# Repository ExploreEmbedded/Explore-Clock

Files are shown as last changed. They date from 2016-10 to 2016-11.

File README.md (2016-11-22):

# FunTime
FunTime is a simple DIY clock kit, that doubles up as automatic night lamp. While building this kit we learn about how time is computed, converted to secs, mins, hours, days and eventually into years! We will also learn about measuring light and controlling a LED depending on time and light. The end goal is build a cool wall clock, use the time and the light intensity to turn on the night lamp. It will take about an hour to solder and assemble the kit.

Get one at:
https://www.exploreembedded.com/product/funTime 

Acrylic Design 
funtime1
PCB

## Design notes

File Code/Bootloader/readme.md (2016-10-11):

Flash the bootloader in the adjacent directory and set the fuse bits as below:
 
 HIGH 0xDA
 LOW 0xE2
 Extended 0xFF

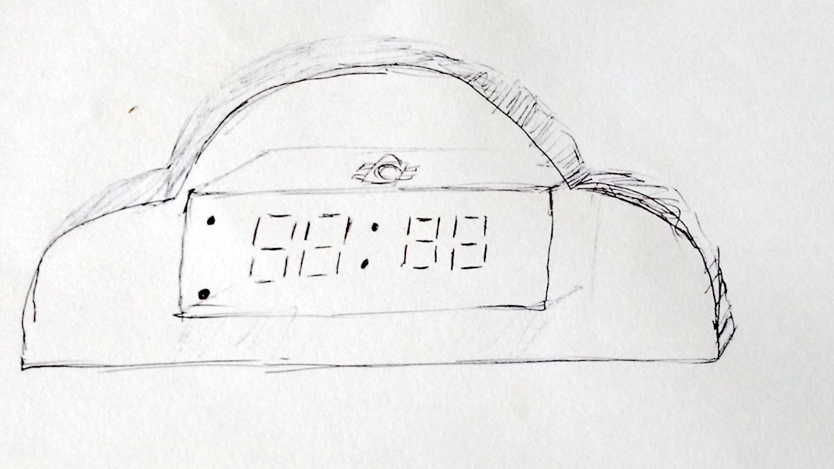
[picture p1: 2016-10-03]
Enclosure/.picasaoriginals/funTime.jpg

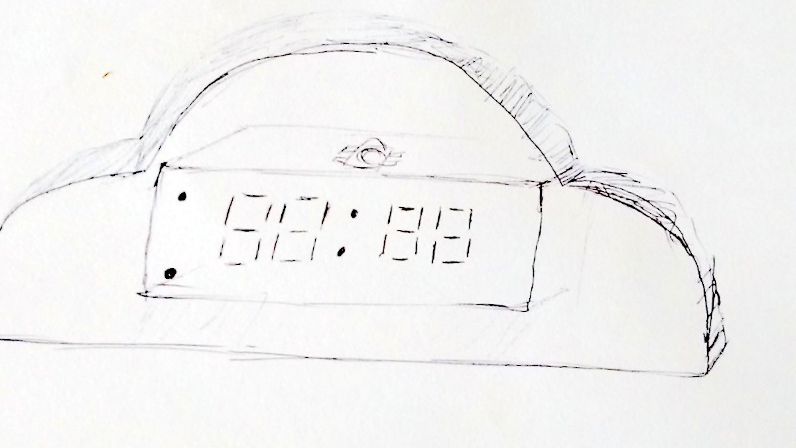
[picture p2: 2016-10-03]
Enclosure/funTime.jpg

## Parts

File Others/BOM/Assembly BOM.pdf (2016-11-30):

SR No. | Designator | Value | Quantity
1 | AFF1 | 4 Digit 7 Segment display ( white ) | 1
2 | C1 | 0.1uF Disc Capacitor | 1
3 | P1 | 01X07 Female Pin Header | 1
4 | R1,R3 | 100K Resistors | 2
5 | R2,R5,R8 | 10K Resistors | 3
6 | R4 | 470E Resistors | 1
7 | R7 | 1K Resistors | 2
8 | R6 | Link (0 ohm) | 1
9 | BT1 | Coin Cell Battery Holder | 1
10 | CON1 | DC Jack | 1
11 | D1 | 5V1 Zener Diode | 1
12 | D2 | 3mm LED | 1
13 | D3 | 8mm 0.5W Straw hat LED | 1
14 | D4,D5 | 1N4148 Diodes | 2
15 | IC1 | ATMEGA328P Controller | 1
16 | Q1 | BC547 NPN Transistor | 1
17 | Q2 | BD139 NPN Transistor | 1
18 | R9 | 47E Resistor | 1
19 | SP1 | Small Buzzer | 1
20 | SW1,SW2 | 25mm Long Tactile Switch | 2
21 | U1 | LDR | 1
22 | Y1 | 32.768KHz Crystal | 1
23 | P2,P3,P4,P5 | M3 Mounting screws and nuts | 8 pair

## FunTime v0.1

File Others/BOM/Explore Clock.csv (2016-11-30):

SR No. | Designator | Value | Quantity
1 | AFF1 | 4 Digit 7 Segment display ( white ) | 1
2 | C1 | 0.1uF Disc Capacitor | 1
3 | P1 | 01X07 Female Pin Header | 1
4 | R1,R3 | 100K Resistors | 2
5 | R2,R5,R8 | 10K Resistors | 3
6 | R4 | 470E Resistors | 1
7 | R6,R7 | 1K Resistors | 2
8 | BT1 | Coin Cell Battery Holder | 1
9 | CON1 | DC Jack | 1
10 | D1 | 5V1 Zener Diode | 1
11 | D2 | 3mm LED | 1
12 | D3 | 8mm 0.5W Straw hat LED | 1
13 | D4,D5 | 1N4148 Diodes | 2
14 | IC1 | ATMEGA328P Controller | 1
15 | Q1 | BC547 NPN Transistor | 1
16 | Q2 | BD139 NPN Transistor | 1
17 | R9 | 47E Resistor | 1
18 | SP1 | Small Buzzer | 1
19 | SW1,SW2 | 25mm Long Tactile Switch | 2
20 | U1 | LDR | 1
21 | Y1 | 32.768KHz Crystal | 1
22 | P2,P3,P4,P5 | M3 Mounting screws and nuts | 8 pair

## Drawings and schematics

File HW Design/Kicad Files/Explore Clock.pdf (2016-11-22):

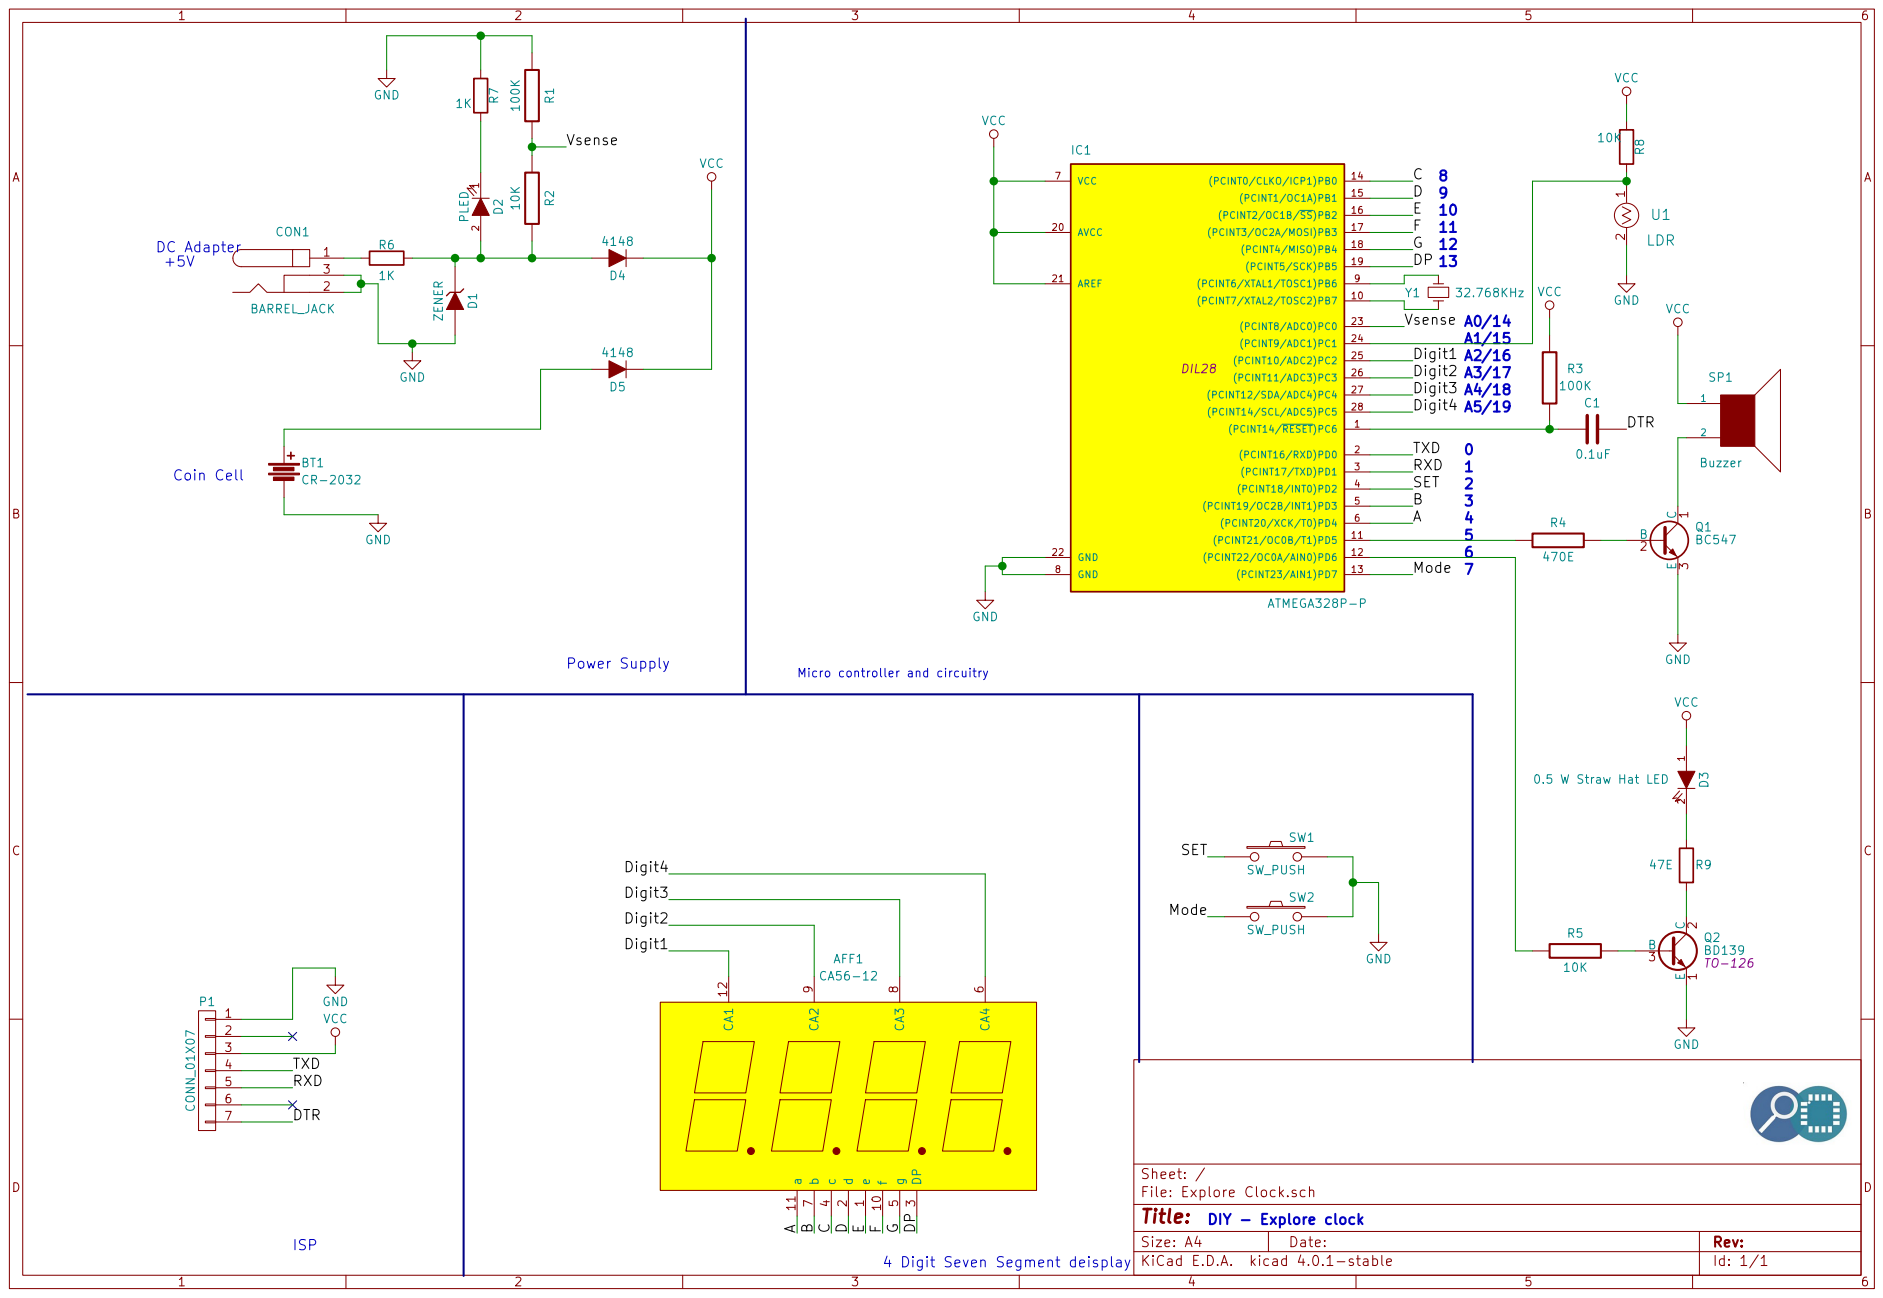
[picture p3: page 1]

File: Explore Clock.sch Sheet: /
Id: 1/1 Title:

4 Digit Seven Segment deisplay

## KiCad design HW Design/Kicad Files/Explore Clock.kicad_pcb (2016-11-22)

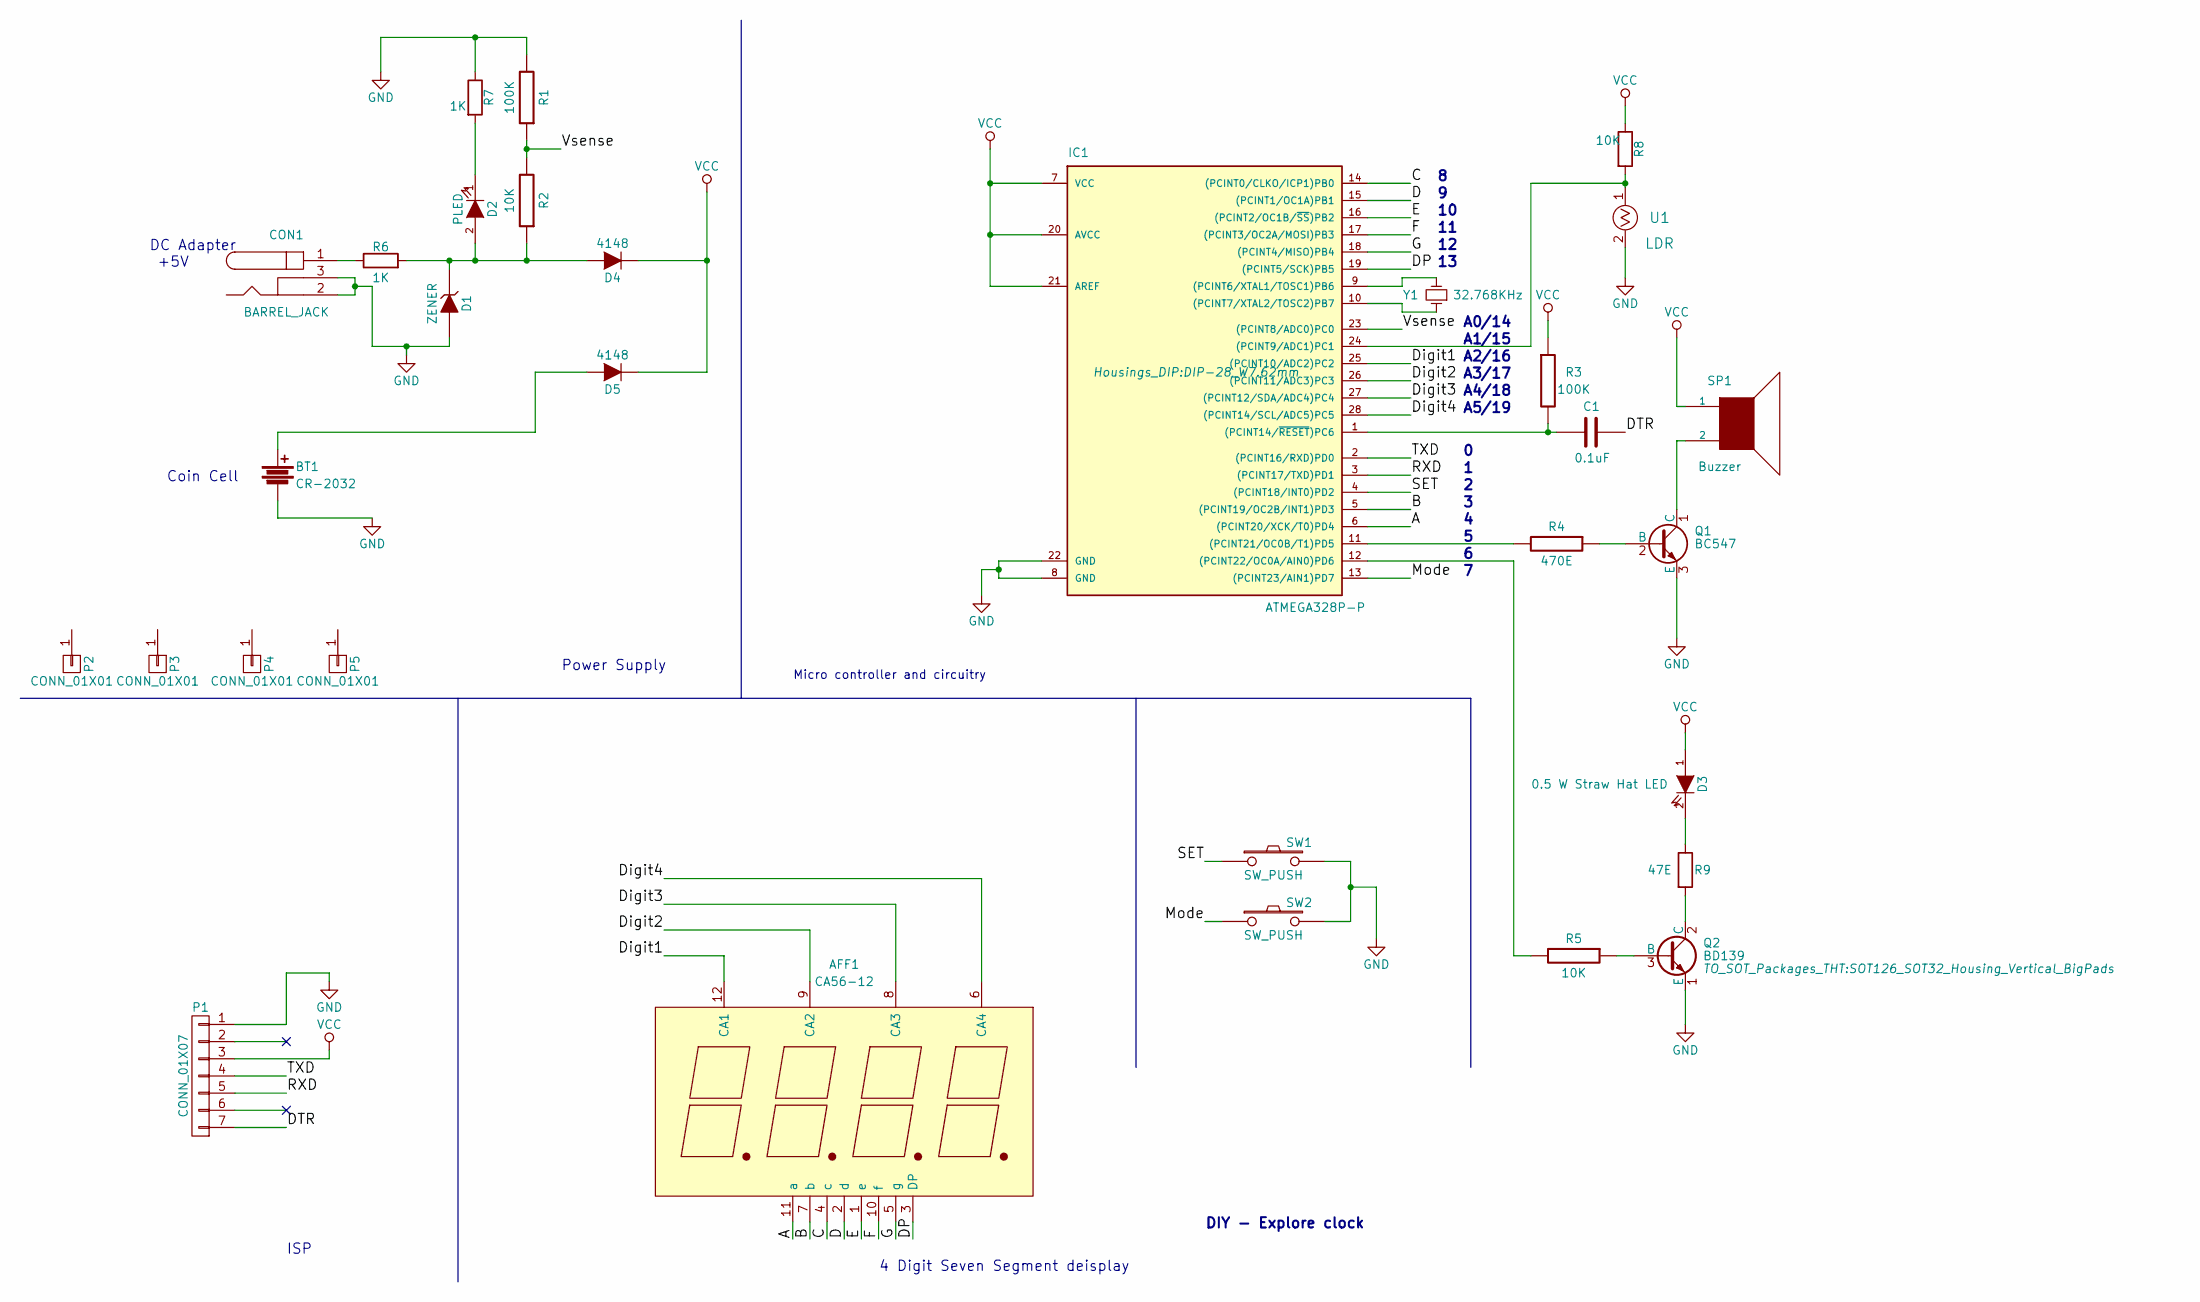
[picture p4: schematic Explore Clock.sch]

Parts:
AFF1: CA56-12; Cx56-12
BT1: CR-2032; BATT_rtc_XL
C1: 0.1uF; C_Disc_D3_P2.5
CON1: BARREL_JACK; JACK_ALIM
D1: ZENER; Diode_DO-41_SOD81_Horizontal_RM10
D2: PLED; LED-3MM
D3: 0.5 W Straw Hat LED; C_Disc_D3_P2.5
D4, D5: 4148; Diode_DO-41_SOD81_Horizontal_RM10
IC1: ATMEGA328P-P; DIP-28_W7.62mm
P1: CONN_01X07; Pin_Header_Straight_1x07
P2, P3, P4, P5: CONN_01X01; M3_mounting
Q1: BC547; TO-92_Molded_Narrow
Q2: BD139; SOT126_SOT32_Housing_Vertical_BigPads
R1, R3: 100K; Resistor_Horizontal_RM10mm
R2, R5, R8: 10K; Resistor_Horizontal_RM10mm
R4: 470E; Resistor_Horizontal_RM10mm
R6, R7: 1K; Resistor_Horizontal_RM10mm
R9: 47E; Resistor_Horizontal_RM10mm
SP1: Buzzer; BUZ3-5
SW1, SW2: SW_PUSH; SW_PUSH_SMALL
U1: LDR; C_Disc_D3_P2.5
Y1: 32.768KHz; RTC_Crystal

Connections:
/A: AFF1.11 (a), IC1.6 ((PCINT20/XCK/T0)PD4)
/B: AFF1.7 (b), IC1.5 ((PCINT19/OC2B/INT1)PD3)
/C: AFF1.4 (c), IC1.14 ((PCINT0/CLKO/ICP1)PB0)
/D: AFF1.2 (d), IC1.15 ((PCINT1/OC1A)PB1)
/DP: AFF1.3 (DP), IC1.19 ((PCINT5/SCK)PB5)
/DTR: C1.1, P1.7
/Digit1: AFF1.12 (CA1), IC1.25 ((PCINT10/ADC2)PC2)
/Digit2: AFF1.9 (CA2), IC1.26 ((PCINT11/ADC3)PC3)
/Digit3: AFF1.8 (CA3), IC1.27 ((PCINT12/SDA/ADC4)PC4)
/Digit4: AFF1.6 (CA4), IC1.28 ((PCINT14/SCL/ADC5)PC5)
/E: AFF1.1 (e), IC1.16 ((PCINT2/OC1B/~SS~)PB2)
/F: AFF1.10 (f), IC1.17 ((PCINT3/OC2A/MOSI)PB3)
/G: AFF1.5 (g), IC1.18 ((PCINT4/MISO)PB4)
/Mode: IC1.13 ((PCINT23/AIN1)PD7), SW2.1
/RXD: IC1.3 ((PCINT17/TXD)PD1), P1.5
/SET: IC1.4 ((PCINT18/INT0)PD2), SW1.1
/TXD: IC1.2 ((PCINT16/RXD)PD0), P1.4
/Vsense: IC1.23 ((PCINT8/ADC0)PC0), R1.1, R2.2
GND: BT1.2, CON1.2, CON1.3, D1.2 (A), IC1.8 (GND), IC1.22 (GND), P1.1, Q1.3 (E), Q2.1 (E), R1.2, R7.1, SW1.2, SW2.2, U1.2
unnamed: BT1.1, D5.2 (A)
unnamed: C1.2, IC1.1 ((PCINT14/~RESET~)PC6), R3.2
unnamed: CON1.1, R6.1
unnamed: D1.1 (K), D2.2 (A), D4.2 (A), R2.1, R6.2
unnamed: D2.1 (K), R7.2
unnamed: D3.2 (K), R9.1
unnamed: IC1.9 ((PCINT6/XTAL1/TOSC1)PB6), Y1.2
unnamed: IC1.10 ((PCINT7/XTAL2/TOSC2)PB7), Y1.1
unnamed: IC1.11 ((PCINT21/OC0B/T1)PD5), R4.2
unnamed: IC1.12 ((PCINT22/OC0A/AIN0)PD6), R5.2
unnamed: IC1.24 ((PCINT9/ADC1)PC1), R8.2, U1.1
unnamed: Q1.1 (C), SP1.2
unnamed: Q1.2 (B), R4.1
unnamed: Q2.2 (C), R9.2
unnamed: Q2.3 (B), R5.1
VCC: D3.1 (A), D4.1 (K), D5.1 (K), IC1.7 (VCC), IC1.20 (AVCC), IC1.21 (AREF), P1.3, R3.1, R8.1, SP1.1

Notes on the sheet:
DIY - Explore clock
DC Adapter +5V
Coin Cell
Power Supply
ISP
4 Digit Seven Segment deisplay
Micro controller and circuitry
/14
/15
/16
/17
/18
/19

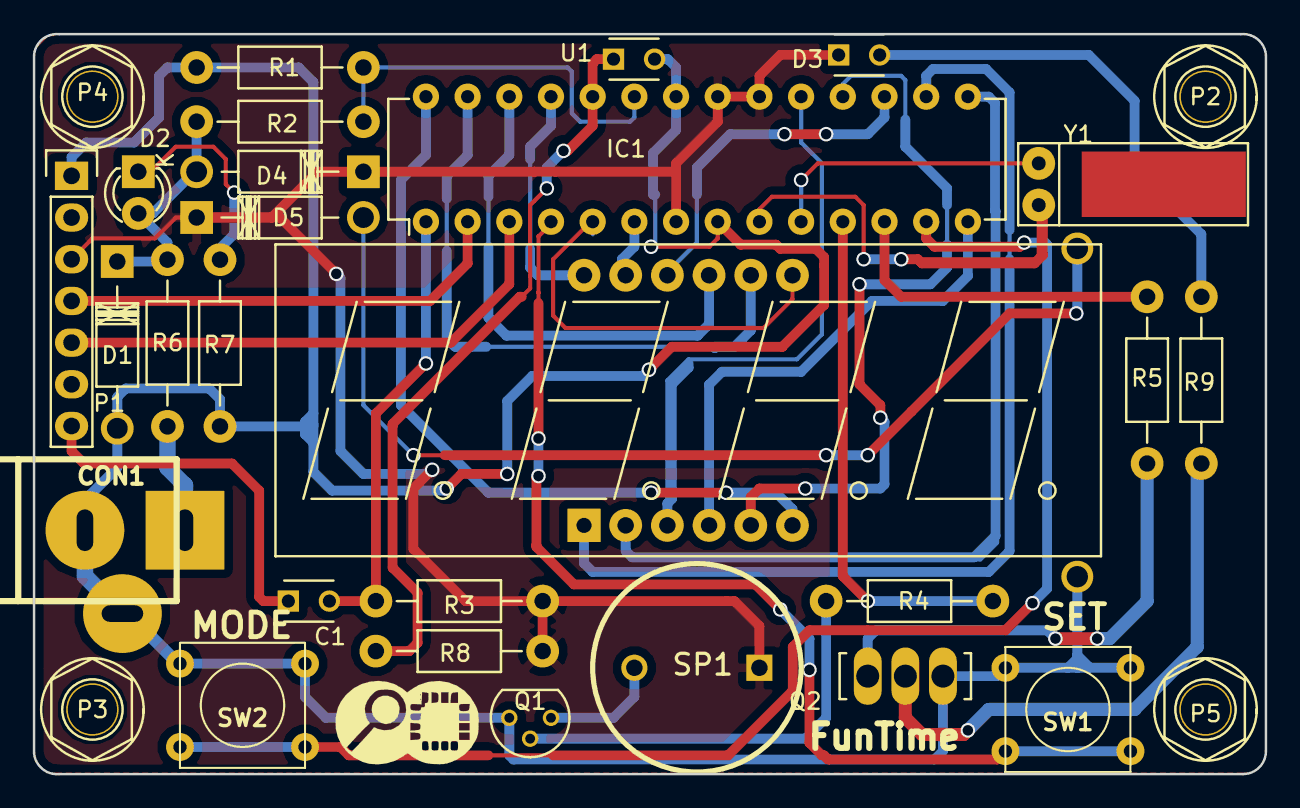
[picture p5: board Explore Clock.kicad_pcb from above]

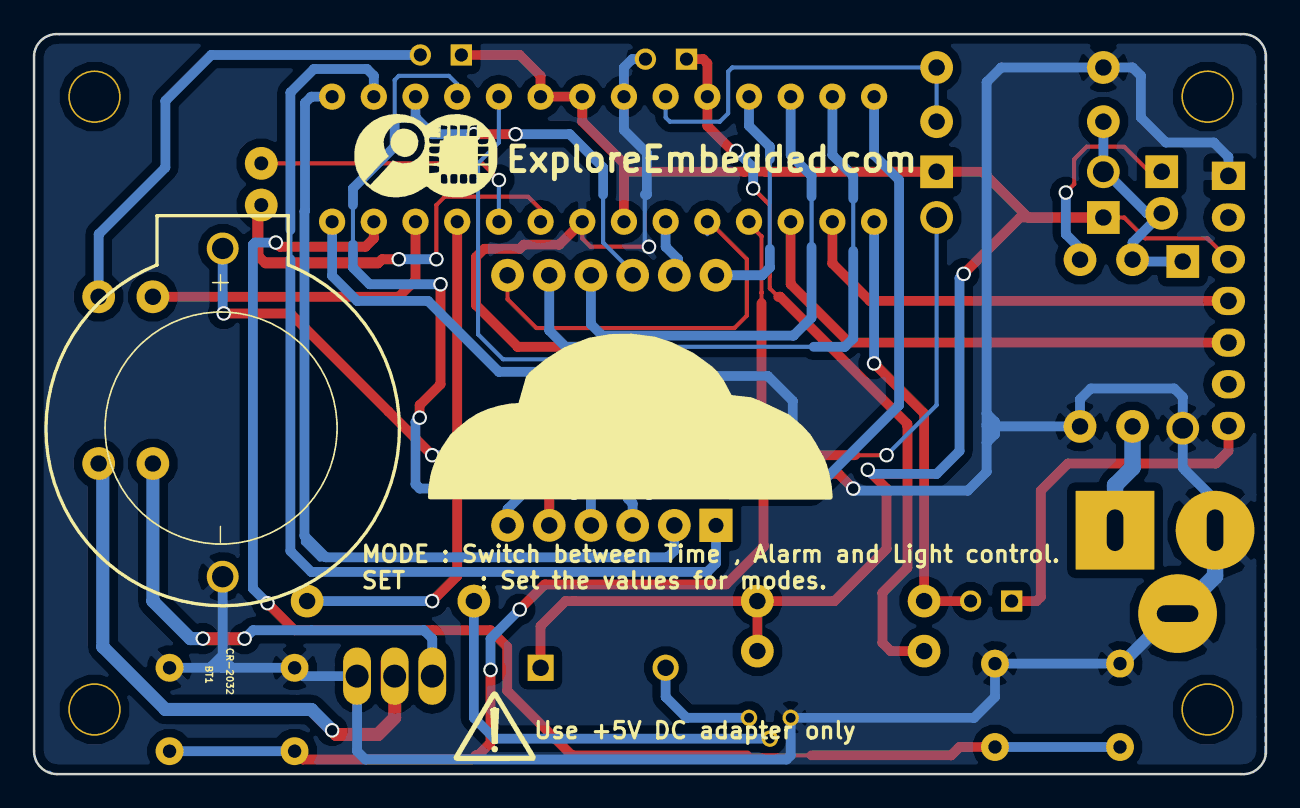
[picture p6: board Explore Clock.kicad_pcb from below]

Board: 2 copper layers, 75.1 x 45.1 mm, 33 parts (2 on the bottom side), 35 nets.

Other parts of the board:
P14, P14#2: CONN_01X01; Logo_8

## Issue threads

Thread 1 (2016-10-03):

Design Considerations

Xplorer001, 2016-10-03:
- [ ] Bigger segments(1.2 inch ?) will aid better visibility. If not readily available we can go with .56 inch ones.
- [ ] Ideas for Acrylic Cases.
- [ ] Test driving circuit for .5W led, that acts as night lamp

raghavendrahassy, 2016-10-03:
0.5W straw hat LED driving circuit.

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

raghavendrahassy, 2016-10-13:
Bigger segments(1.2 inch ?) will aid better visibility. If not readily available we can go with .56 inch ones.
This can be implemented in the next the revision.
 Ideas for Acrylic Cases.
Done
 Test driving circuit for .5W led, that acts as night lamp
Designed using BD139 Transistor

Closed 2016-10-13.

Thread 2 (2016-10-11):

Pin Assigments

Xplorer001, 2016-10-11:
- Change **SET** PIN to Arduino **PIN 2** (PORTD2) for using interrupt to walk from sleep and check time.
- Change **A** to Arduino **PIN 4**
- Set Value of R1 TO 100K and R2 to 10K
- Add zener diode of 5.1v break down across dc adapter input.

raghavendrahassy, 2016-10-13:
Changes has been done

Closed 2016-10-13.

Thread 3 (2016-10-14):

Modifications needs to be done for acrylic case

raghavendrahassy, 2016-10-14:
@sharanago  :
1. Modify case design as per finalised PCB.
2. Design cases for 5mm thickness acrylic sheet.
3. Routing should be 1.5mm to 2mm inside the edges of the acrylic sheet.
4. Maintain above 2.5 mm clearance between front and rear plate.
5. Provide 2 openings on the top plate for 0.5W LED and LDR.

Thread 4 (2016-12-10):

List of Modifications needs be done

raghavendrahassy, 2016-12-10:
- Buzzer ploarity needs to be added on silkscreen.

-  Coin cell battery needs to be placed out of display surrounding.

-  Controller base pin 1 notch should be added on silkscreen and its need little clearance from
the display.

- BD139 Silkscreen orientation.

- LDR pin spacing needs to be increased.

- Straw hat LED footprint needs to be changed, also indicate the polarity on silkscreen.

- Shift R5 and R9 resistors from coin cell battery area.

- Change the R6 value from 1K to 0Ohm.

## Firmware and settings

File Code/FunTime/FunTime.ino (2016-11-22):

/*
	

 Firmware for FunTime DIY wall clock.  The clock is based on the the popular Atmega328 running on Internal 8Mhz oscillator. The clock uses Timer 1 with 32.686kHz ocillator to keep time. The clock is powered by 5V DC adapter, in case
 of power outage, it automatically switches to the CR2032 coin cell battery and enters sleep mode for power saving.

 The night lamp, simply turns on if it is dark. You can set the value depending on lighting conditions of your house. The higher the value of 
 sensor, the darker is the room.
 
 For more:
 https://github.com/ExploreEmbedded/FunTime 
 
 

 Internal 8MHz
 Clock div 8 cleared
 Brown out detect disabled
 BOOTRST set
 BOOSZ = 1024 
 This is to save power and open up the XTAL pins for use with a 38.786kHz external osc.
 
 So the fuse bits I get using AVR studio:
 HIGH 0xDA
 LOW 0xE2
 Extended 0xFF  
 
 3,600 seconds in an hour
 1 time check per hour, 2 seconds at 13mA
 3,598 seconds @ 1.2uA
 (3598 / 3600) * 0.0012mA + (2 / 3600) * 13mA = 0.0084mA used per hour
 
 200mAh / 0.0084mA = 23,809hr = 992 days = 2.7 years
 

 References and Credits:
 Inspirted by the BigTime kit from Sparkfun. 
 https://github.com/sparkfun/BigTime 

 To Do:

 Add alarm functionality.
 Option to set light intensity with the switches. The light sensor value can be linearly mapped from 0 to 99. 
 
 
 */
#include "main.h"

#include <avr/sleep.h> //Needed for sleep_mode
#include <avr/power.h> //Needed for powering down perihperals such as the ADC/TWI and Timers



//Set the 12hourMode to false for military/world time. Set it to true for American 12 hour time.
int TwelveHourMode = true;

//Set this variable to change how long the time is shown on the watch face. In milliseconds so 1677 = 1.677 seconds
int show_time_length = 5000;
int show_the_time = false;

//You can set always_on to true and the display will stay on all the time
//This will drain the battery in about 15 hours 
int always_on = false;

long seconds = 55;
int minutes = 19;
int hours = 10;

//Careful messing with the system color, you can damage the display if
//you assign the wrong color. If you're in doubt, set it to red and load the code,
//then see what the color is.
#define RED  1
#define GREEN 2
#define BLUE  3
#define YELLOW  4
int systemColor = RED;
int display_brightness = 15000; //A larger number makes the display more dim. This is set correctly below.


//Power Source

#define BATTERY 0
#define DC 1

boolean pwrSource =  BATTERY ;

//-=-=-=-=-=-=-=-=-=-=-=-=-=-=-=-=-=-=
//Pin definitions
int digit1 = A2; //Display pin 1
int digit2 = A3; //Display pin 2
int digit3 = A4; //Display pin 6
int digit4 = A5; //Display pin 8

int segA = 4; //Display pin 14
int segB = 3; //Display pin 16
int segC = 8; //Display pin 13
int segD = 9; //Display pin 3
int segE = 10; //Display pin 5
int segF = 11; //Display pin 11
int segG = 12; //Display pin 15

int colons = 13; //Display pin 4

//need to remove this
int lightSensor = A1; //Display pin 10

int theButton = 2;

int pwrSense = A0; 

int ampm = 13;

int nightLamp = 6;

static boolean blinkColon = 0;
//-=-=-=-=-=-=-=-=-=-=-=-=-=-=-=-=-=-=

//The very important 32.686kHz interrupt handler
SIGNAL(TIMER2_OVF_vect){
  seconds += 8; //We sleep for 8 seconds instead of 1 to save more power
 // seconds++; //Use this if we are waking up every second

  //Update the minutes and hours variables
  minutes += seconds / 60; //Example: seconds = 2317, minutes = 58 + 38 = 96
  seconds %= 60; //seconds = 37
  hours += minutes / 60; //12 + (96 / 60) = 13
  minutes %= 60; //minutes = 36

  //Do we display 12 hour or 24 hour time?
  if(TwelveHourMode == true) {
    //In 12 hour mode, hours go from 12 to 1 to 12.
    while(hours > 12) hours -= 12;
  }
  else {
    //In 24 hour mode, hours go from 0 to 23 to 0.
    while(hours > 23) hours -= 24;
  }
}

////The interrupt occurs when you push the button
SIGNAL(INT0_vect){
  //When you hit the button, we will need to display the time
  //if(show_the_time == false) 
  show_the_time = true;
}

void setup() {

  

   
  //To reduce power, setup all pins as inputs with no pullups
  for(int x = 1 ; x < 18 ; x++){
    pinMode(x, INPUT);
    digitalWrite(x, LOW);
  }

  pinMode(theButton, INPUT); //This is the main button, tied to INT0
  digitalWrite(theButton, HIGH); //Enable internal pull up on button

  //These pins are used to control the display
  pinMode(segA, OUTPUT);
  pinMode(segB, OUTPUT);
  pinMode(segC, OUTPUT);
  pinMode(segD, OUTPUT);
  pinMode(segE, OUTPUT);
  pinMode(segF, OUTPUT);
  pinMode(segG, OUTPUT);

  pinMode(digit1, OUTPUT);
  pinMode(digit2, OUTPUT);
  pinMode(digit3, OUTPUT);
  pinMode(digit4, OUTPUT);
  pinMode(colons, OUTPUT);
  pinMode(ampm, OUTPUT);

  pinMode(pwrSense, INPUT);
  pinMode(nightLamp, OUTPUT);

  //digitalWrite(nightLamp, HIGH);

  //Power down various bits of hardware to lower power usage  
  set_sleep_mode(SLEEP_MODE_PWR_SAVE);
  sleep_enable();

    //Shut off ADC, TWI, SPI, Timer0, Timer1

  //ADCSRA &= ~(1<<ADEN); //Disable ADC
  ACSR = (1<<ACD); //Disable the analog comparator
 // DIDR0 = 0x3F; //Disable digital input buffers on all ADC0-ADC5 pins
 // DIDR1 = (1<<AIN1D)|(1<<AIN0D); //Disable digital input buffer on AIN1/0

  power_twi_disable();
  power_spi_disable();
  //  power_usart0_disable(); //Needed for serial.print
  //power_timer0_disable(); //Needed for delay and millis()
  power_timer1_disable();
  //power_timer2_disable(); //Needed for asynchronous 32kHz operation

  //Setup TIMER2
  TCCR2A = 0x00;
  //TCCR2B = (1<<CS22)|(1<<CS20); //Set CLK/128 or overflow interrupt every 1s
  TCCR2B = (1<<CS22)|(1<<CS21)|(1<<CS20); //Set CLK/1024 or overflow interrupt every 8s
  ASSR = (1<<AS2); //Enable asynchronous operation
  TIMSK2 = (1<<TOIE2); //Enable the timer 2 interrupt

  //Setup external INT0 interrupt
  // EICRA = (1<<ISC01); //Interrupt on falling edge
  //EIMSK = (1<<INT0); //Enable INT0 interrupt

  //System clock futzing
  //CLKPR = (1<<CLKPCE); //Enable clock writing
  //CLKPR = (1<<CLKPS3); //Divid the system clock by 256

  Serial.begin(9600);  
  Serial.println("BigTime Testing:");

  //Now display the system color - this is mostly for production to verify
  //that the correct code is loaded onto the ATmega
  //Display brightness changes based on color
  if(systemColor == RED) {
    display_brightness = 3000; //The higher the number, the lower the brightness
    showColor("red ");
  }
  else if(systemColor == GREEN) {
    display_brightness = 1;
    showColor("gren");
  }
  else if(systemColor == BLUE) {
    display_brightness = 1; //Works well for blue displays, uses about 5.5mA
    showColor("bLue");
  }
  else if(systemColor == YELLOW) {
    //display_brightness = 1500;
    display_brightness = 1;
    showColor("yeLo");
  }

  //  showTime(); //Show the current time for a few seconds

  sei(); //Enable global interrupts
}

void loop() {

 
   
   
   
  
   if(digitalRead(pwrSense)){
      //sleep_mode();
      //Serial.println("dc jack");
        always_on = true;
        Serial.println(analogRead(lightSensor));
        if(analogRead(lightSensor) > 700) //if it dark, turn ON the night lamp
        {
          digitalWrite(nightLamp, HIGH);
        }
        else
        {  
          digitalWrite(nightLamp, LOW);
        }
      
    } 
   else{
     // Serial.println("battery");    
      always_on = false;
   }
   
   
   if(always_on == false){

   // Serial.println("Entering sleep mode");
    digitalWrite(colons, HIGH);
    sleep_mode(); //Stop everything and go to sleep. Wake up if the Timer2 buffer overflows or if you hit the button

   }

  if(show_the_time == true || always_on == true) {
    
    //Debounce
    while(digitalRead(theButton) == LOW) ; //Wait for you to remove your finger
    delay(100);
    while(digitalRead(theButton) == LOW) ; //Wait for you to remove your finger

//     Serial.print(hours, DEC);
//     Serial.print(":");
//     Serial.print(minutes, DEC);
//     Serial.print(":");
//     Serial.println(seconds, DEC);

    showTime(); //Show the current time for a few seconds

    //If you are STILL holding the button, then you must want to adjust the time
    if(digitalRead(theButton) == LOW) setTime();

    show_the_time = false; //Reset the button variable

    

  }

  
  
}

void showTime() {

  //Here is where we display the time and PWM the segments
  //Display brightness changes based on color, red is too bright, blue is very dull
  //By painting the time, then turning off for a number of microseconds, we can control how bright the display is

  //Each digit is on for a certain amount of microseconds
  //Then it is turned off and we go to the next digit
  //We loop through each digit until we reach the show_time_length (usually about 2 seconds)

  //For the default red display:
  //Let's define a variable called display_brightness that varies from:
  //5000 blindingly bright (15.7mA current draw per digit)
  //2000 shockingly bright (11.4mA current draw per digit)
  //1000 pretty bright (5.9mA)
  //500 normal (3mA)
  //200 dim but readable (1.4mA)
  //50 dim but readable (0.56mA)
  //5 dim but readable (0.31mA)
  //1 dim but readable in dark (0.28mA)

  int combinedTime = (hours * 100) + minutes; //Combine the hours and minutes
  //int combinedTime = (minutes * 100) + seconds; //For testing, combine the minutes and seconds

  boolean buttonPreviouslyHit = false;

  //Now show the time for a certain length of time
  long startTime = millis();
  while( (millis() - startTime) < show_time_length) {
    displayNumber(combinedTime, true); //Each call takes about 8ms, display the colon

    //After the time is displayed, the segments are turned off
    //We control the brightness by modifying how long we wait between re-paints of the display
    //delayMicroseconds(display_brightness);

    //If you have hit and released the button while the display is on, start the IR off sequence
    if(digitalRead(theButton) == LOW) {
      buttonPreviouslyHit = true;
    }
    else if( (buttonPreviouslyHit == true) && (digitalRead(theButton) == HIGH) ) {

	//removed tv bogone.	
      return;
    }      
  }

}

//Displays a string on the display
//Used to indicate which code is loaded onto the watch
void showColor(char *colorName) {

  //Now show the letters for a certain length of time
  long startTime = millis();
  while( (millis() - startTime) < show_time_length) {
    displayLetters(colorName); //Each call takes about 8ms, display the colon

    //After the letters are displayed, the segments are turned off
    //We control the brightness by modifying how long we wait between re-paints of the display
    delayMicroseconds(display_brightness);
  }
}

//This routine occurs when you hold the button down
//The colon blinks indicating we are in this mode
//Holding the button down will increase the time (accelerates)
//Releasing the button for more than 2 seconds will exit this mode
void setTime(void) {

  int idleMiliseconds = 0;
  //This is the timeout counter. Once we get to ~2 seconds of inactivity, the watch
  //will exit the setTime function and return to normal operation

  int buttonHold = 0; 
  //This counts the number of times you are holding the button down consecutively
  //Once we notice you're really holding the button down a lot, we will speed up the minute counter

  while(idleMiliseconds < 2000) {

    cli(); //We don't want the interrupt changing values at the same time we are!

    //Update the minutes and hours variables
    minutes += seconds / 60; //Example: seconds = 2317, minutes = 58 + 38 = 96
    seconds %= 60; //seconds = 37
    hours += minutes / 60; //12 + (96 / 60) = 13
    minutes %= 60; //minutes = 36

    //Do we display 12 hour or 24 hour time?
    if(TwelveHourMode == true) {
      //In 12 hour mode, hours go from 12 to 1 to 12.
      while(hours > 12) hours -= 12;
    }
    else {
      //In 24 hour mode, hours go from 0 to 23 to 0.
      while(hours > 23) hours -= 24;
    }

    sei(); //Resume interrupts

    int combinedTime = (hours * 100) + minutes; //Combine the hours and minutes

      for(int x = 0 ; x < 10 ; x++) {
      displayNumber(combinedTime, true); //Each call takes about 8ms, display the colon for about 100ms
      delayMicroseconds(display_brightness); //Wait before we paint the display again
    }
    for(int x = 0 ; x < 10 ; x++) {
      displayNumber(combinedTime, false); //Each call takes about 8ms, turn off the colon for about 100ms
      delayMicroseconds(display_brightness); //Wait before we paint the display again
    }

    //If you're still hitting the button, then increase the time and reset the idleMili timeout variable
    if(digitalRead(theButton) == LOW) {
      idleMiliseconds = 0;

      buttonHold++;
      if(buttonHold < 10) //10 = 2 seconds
        minutes++; //Advance the minutes
      else {
        //Advance the minutes faster because you're holding the button for 10 seconds
        //Start advancing on the tens digit. Floor the single minute digit.
        minutes /= 10; //minutes = 46 / 10 = 4
        minutes *= 10; //minutes = 4 * 10 = 40
        minutes += 10;  //minutes = 40 + 10 = 50
      }
    }
    else
      buttonHold = 0;

    idleMiliseconds += 200;
  }
}

//This is a not-so-accurate delay routine
//Calling fake_msdelay(100) will delay for about 100ms
//Assumes 8MHz clock
/*void fake_msdelay(int x){
 for( ; x > 0 ; x--)
 fake_usdelay(1000);
 }*/

//This is a not-so-accurate delay routine
//Calling fake_usdelay(100) will delay for about 100us
//Assumes 8MHz clock
/*void fake_usdelay(int x){
 for( ; x > 0 ; x--) {
 __asm__("nop\n\t"); 
 __asm__("nop\n\t"); 
 __asm__("nop\n\t"); 
 __asm__("nop\n\t"); 
 __asm__("nop\n\t"); 
 __asm__("nop\n\t"); 
 __asm__("nop\n\t"); 
 }
 }*/

//Given 1022, we display "10:22"
//Each digit is displayed for ~2000us, and cycles through the 4 digits
//After running through the 4 numbers, the display is turned off
void displayNumber(int toDisplay, boolean displayColon) {

#define DIGIT_ON  HIGH
#define DIGIT_OFF  LOW

  for(int digit = 4 ; digit > 0 ; digit--) {

    //Turn on a digit for a short amount of time
    switch(digit) {
    case 1:
      digitalWrite(digit1, DIGIT_ON);
      break;
    case 2:
      digitalWrite(digit2, DIGIT_ON);
      break;
    case 3:
      digitalWrite(digit3, DIGIT_ON);
      if(displayColon == true){             
            //Serial.print(blinkColon); 
            digitalWrite(colons, blinkColon);  
        }//When we update digit 2, let's turn on colons as well
      break;
    case 4:
      digitalWrite(digit4, DIGIT_ON);
      if(displayColon == true){ 
           // Serial.print(blinkColon); 
            digitalWrite(colons, blinkColon);      
        }//When we update digit 2, let's turn on colons as well
      break;
    }

    //Now display this digit
    if(digit > 1)
      lightNumber(toDisplay % 10); //Turn on the right segments for this digit
    else if(digit == 1) { //Special case on first digit, don't display 02:11, display 2:11
      if( (toDisplay % 10) != 0) //If we are on the first digit, and it's not zero
        lightNumber(toDisplay % 10); //Turn on the right segments for this digit
    }

    toDisplay /= 10;

    delayMicroseconds(2000); //Display this digit for a fraction of a second (between 1us and 5000us, 500-2000 is pretty good)
    //If you set this too long, the display will start to flicker. Set it to 25000 for some fun.

    //Turn off all segments
    lightNumber(10);

    //Turn off all digits
    digitalWrite(digit1, DIGIT_OFF);
    digitalWrite(digit2, DIGIT_OFF);
    digitalWrite(digit3, DIGIT_OFF);
    digitalWrite(digit4, DIGIT_OFF);
    digitalWrite(colons, DIGIT_OFF);
    digitalWrite(ampm, DIGIT_OFF);
  }

}

//Takes a string like "gren" and displays it, left justified
//We don't use the colons, or AMPM dot, so they are turned off
void displayLetters(char *colorName) {
#define DIGIT_ON  HIGH
#define DIGIT_OFF  LOW

  digitalWrite(digit4, DIGIT_OFF);
  digitalWrite(colons, DIGIT_OFF);
  digitalWrite(ampm, DIGIT_OFF);

  for(int digit = 0 ; digit < 4 ; digit++) {
    //Turn on a digit for a short amount of time
    switch(digit) {
    case 0:
      digitalWrite(digit1, DIGIT_ON);
      break;
    case 1:
      digitalWrite(digit2, DIGIT_ON);
      break;
    case 2:
      digitalWrite(digit3, DIGIT_ON);
      break;
    case 3:
      digitalWrite(digit4, DIGIT_ON);
      break;
    }

    //Now display this letter
    lightNumber(colorName[digit]); //Turn on the right segments for this letter

    delayMicroseconds(2000); //Display this digit for a fraction of a second (between 1us and 5000us, 500-2000 is pretty good)
    //If you set this too long, the display will start to flicker. Set it to 25000 for some fun.

    //Turn off all segments
    lightNumber(10);

    //Turn off all digits
    digitalWrite(digit1, DIGIT_OFF);
    digitalWrite(digit2, DIGIT_OFF);
    digitalWrite(digit3, DIGIT_OFF);
  }
}

//Given a number, turns on those segments
//If number == 10, then turn off all segments
void lightNumber(int numberToDisplay) {

#define SEGMENT_ON  LOW
#define SEGMENT_OFF HIGH

  /*
Segments
   -  A
   F / / B
   -  G
   E / / C
   -  D
   */

  switch (numberToDisplay){

  case 0:
    digitalWrite(segA, SEGMENT_ON);
    digitalWrite(segB, SEGMENT_ON);
    digitalWrite(segC, SEGMENT_ON);
    digitalWrite(segD, SEGMENT_ON);
    digitalWrite(segE, SEGMENT_ON);
    digitalWrite(segF, SEGMENT_ON);
    break;

  case 1:
    digitalWrite(segB, SEGMENT_ON);
    digitalWrite(segC, SEGMENT_ON);
    break;

  case 2:
    digitalWrite(segA, SEGMENT_ON);
    digitalWrite(segB, SEGMENT_ON);
    digitalWrite(segD, SEGMENT_ON);
    digitalWrite(segE, SEGMENT_ON);
    digitalWrite(segG, SEGMENT_ON);
    break;

  case 3:
    digitalWrite(segA, SEGMENT_ON);
    digitalWrite(segB, SEGMENT_ON);
    digitalWrite(segC, SEGMENT_ON);
    digitalWrite(segD, SEGMENT_ON);
    digitalWrite(segG, SEGMENT_ON);
    break;

  case 4:
    digitalWrite(segB, SEGMENT_ON);
    digitalWrite(segC, SEGMENT_ON);
    digitalWrite(segF, SEGMENT_ON);
    digitalWrite(segG, SEGMENT_ON);
    break;

  case 5:
    digitalWrite(segA, SEGMENT_ON);
    digitalWrite(segC, SEGMENT_ON);
    digitalWrite(segD, SEGMENT_ON);
    digitalWrite(segF, SEGMENT_ON);
    digitalWrite(segG, SEGMENT_ON);
    break;

  case 6:
    digitalWrite(segA, SEGMENT_ON);
    digitalWrite(segC, SEGMENT_ON);
    digitalWrite(segD, SEGMENT_ON);
    digitalWrite(segE, SEGMENT_ON);
    digitalWrite(segF, SEGMENT_ON);
    digitalWrite(segG, SEGMENT_ON);
    break;

  case 7:
    digitalWrite(segA, SEGMENT_ON);
    digitalWrite(segB, SEGMENT_ON);
    digitalWrite(segC, SEGMENT_ON);
    break;

  case 8:
    digitalWrite(segA, SEGMENT_ON);
    digitalWrite(segB, SEGMENT_ON);
    digitalWrite(segC, SEGMENT_ON);
    digitalWrite(segD, SEGMENT_ON);
    digitalWrite(segE, SEGMENT_ON);
    digitalWrite(segF, SEGMENT_ON);
    digitalWrite(segG, SEGMENT_ON);
    break;

  case 9:
    digitalWrite(segA, SEGMENT_ON);
    digitalWrite(segB, SEGMENT_ON);
    digitalWrite(segC, SEGMENT_ON);
    digitalWrite(segD, SEGMENT_ON);
    digitalWrite(segF, SEGMENT_ON);
    digitalWrite(segG, SEGMENT_ON);
    break;

  case 10:
    digitalWrite(segA, SEGMENT_OFF);
    digitalWrite(segB, SEGMENT_OFF);
    digitalWrite(segC, SEGMENT_OFF);
    digitalWrite(segD, SEGMENT_OFF);
    digitalWrite(segE, SEGMENT_OFF);
    digitalWrite(segF, SEGMENT_OFF);
    digitalWrite(segG, SEGMENT_OFF);
    break;

    /*
Segments
     -  A
     F / / B
     -    G
     E / / C
     - D
     */

    //Letters
  case 'b': //cdefg
    digitalWrite(segC, SEGMENT_ON);
    digitalWrite(segD, SEGMENT_ON);
    digitalWrite(segE, SEGMENT_ON);
    digitalWrite(segF, SEGMENT_ON);
    digitalWrite(segG, SEGMENT_ON);
    break;
  case 'L': //def
    digitalWrite(segD, SEGMENT_ON);
    digitalWrite(segE, SEGMENT_ON);
    digitalWrite(segF, SEGMENT_ON);
    break;
  case 'u': //cde
    digitalWrite(segC, SEGMENT_ON);
    digitalWrite(segD, SEGMENT_ON);
    digitalWrite(segE, SEGMENT_ON);
    break;

  case 'g': //abcdfg
    digitalWrite(segA, SEGMENT_ON);
    digitalWrite(segB, SEGMENT_ON);
    digitalWrite(segC, SEGMENT_ON);
    digitalWrite(segD, SEGMENT_ON);
    digitalWrite(segF, SEGMENT_ON);
    digitalWrite(segG, SEGMENT_ON);
    break;
  case 'r': //eg
    digitalWrite(segE, SEGMENT_ON);
    digitalWrite(segG, SEGMENT_ON);
    break;
  case 'n': //ceg
    digitalWrite(segC, SEGMENT_ON);
    digitalWrite(segE, SEGMENT_ON);
    digitalWrite(segG, SEGMENT_ON);
    break;

    //case r
  case 'e': //adefg
    digitalWrite(segA, SEGMENT_ON);
    digitalWrite(segD, SEGMENT_ON);
    digitalWrite(segE, SEGMENT_ON);
    digitalWrite(segF, SEGMENT_ON);
    digitalWrite(segG, SEGMENT_ON);
    break;
  case 'd': //bcdeg
    digitalWrite(segB, SEGMENT_ON);
    digitalWrite(segC, SEGMENT_ON);
    digitalWrite(segD, SEGMENT_ON);
    digitalWrite(segE, SEGMENT_ON);
    digitalWrite(segG, SEGMENT_ON);
    break;
  case ' ': //None
    digitalWrite(segA, SEGMENT_OFF);
    digitalWrite(segB, SEGMENT_OFF);
    digitalWrite(segC, SEGMENT_OFF);
    digitalWrite(segD, SEGMENT_OFF);
    digitalWrite(segE, SEGMENT_OFF);
    digitalWrite(segF, SEGMENT_OFF);
    digitalWrite(segG, SEGMENT_OFF);
    break;

  case 'y': //bcdfg
    digitalWrite(segB, SEGMENT_ON);
    digitalWrite(segC, SEGMENT_ON);
    digitalWrite(segD, SEGMENT_ON);
    digitalWrite(segF, SEGMENT_ON);
    digitalWrite(segG, SEGMENT_ON);
    break;
    //case e 
    //case L
  case 'o': //cdeg
    digitalWrite(segC, SEGMENT_ON);
    digitalWrite(segD, SEGMENT_ON);
    digitalWrite(segE, SEGMENT_ON);
    digitalWrite(segG, SEGMENT_ON);
    break;

  }
}

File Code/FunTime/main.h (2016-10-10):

#include <avr/pgmspace.h>


// The TV-B-Gone for Arduino can use
//   either the EU or the NA database of POWER CODES
// EU is for Europe, Middle East, Australia, New Zealand, and some countries in Africa and South America
// NA is for North America, Asia, and the rest of the world not covered by EU

// Two regions!
#define NA 1
#define EU 0

// What pins do what
#define DBG 12
#define LED 12 //Colons on BigTime
#define IRLED 3
#define TRIGGER 2
#define REGIONSWITCH 5

// Lets us calculate the size of the NA/EU databases
#define NUM_ELEM(x) (sizeof (x) / sizeof (*(x)));

// set define to 0 to turn off debug output
#define DEBUG 0
#define DEBUGP(x) if (DEBUG == 1) { x ; }

// Shortcut to insert single, non-optimized-out nop
#define NOP __asm__ __volatile__ ("nop")

// Tweak this if neccessary to change timing
//#define DELAY_CNT 25 //16MHz
#define DELAY_CNT 11 //8MHz

// Makes the codes more readable. the OCRA is actually
// programmed in terms of 'periods' not 'freqs' - that
// is, the inverse!
#define freq_to_timerval(x) (F_CPU / 8 / x - 1)

// The structure of compressed code entries
struct IrCode {
  uint8_t timer_val;
  uint8_t numpairs;
  uint8_t bitcompression;
  uint16_t const *times;
  uint8_t const*codes;
};

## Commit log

2016-10-01 Schematic Update
    [Explore Clock.kicad_pcb, Explore Clock.sch]
2016-10-03 design idea for the case
2016-10-03 sketch to test power source
2016-10-04 Added LDR, Changed Vsense ciruit
    [Explore Clock.sch]
2016-10-04 0.5W LED Driving circuit added
    [Explore Clock.sch]
2016-10-06 Power LED added
    [Explore Clock.sch]
2016-10-07 Layout For pcb and Acrylic Design Uploaded
    [Explore Clock.sch]
2016-10-10 renamed imp directories, test code added
    [Explore Clock.kicad_pcb, Explore Clock.sch]
2016-10-11 added bootloader hex and fuse bits
2016-10-11 Added hole for LDR in Acrylic case
2016-10-13 added zener diode , INT0 used for switch SET and BD139 for LED
    [Explore Clock.sch]
2016-10-14 Kicad Design files ready for manufacturing
    [Explore Clock-B.Cu.gbr, Explore Clock-B.Mask.gbr, Explore Clock-B.SilkS.gbr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]
2016-11-30 Acrylic Enclosure design updated for 5mm sheet
2016-11-30 Assemly BOM Generated
    [Assembly BOM.xls, Explore Clock.csv, _saved_Explore Clock.sch]
